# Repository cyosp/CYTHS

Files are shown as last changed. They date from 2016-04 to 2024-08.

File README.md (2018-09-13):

# CYTHS

A 433 MHz Temperature and Humidity Solution

This project is divided in several parts:
 * [A sensor](hardware/sensor/V2.0) which measures and sends temperature and humidity

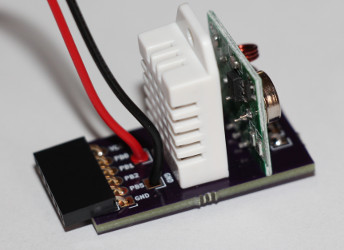
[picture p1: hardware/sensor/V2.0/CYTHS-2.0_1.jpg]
CYTHS-2.0_1
 

 * [A hardware](hardware/piTransceiver/V1.0) part connected to a [Raspberry Pi](https://www.raspberrypi.org/products/) in order to:
    * Receive sensors information
    * Drive RSL switch connected to electric heaters

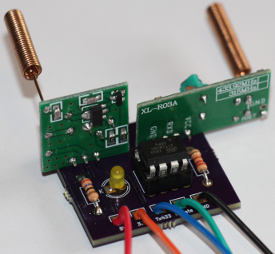
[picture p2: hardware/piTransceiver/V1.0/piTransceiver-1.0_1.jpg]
piTransceiver-1.0_1
    

 * A software part hosted by the [Raspberry Pi](https://www.raspberrypi.org/products/) which:
    * Drives RSL switches

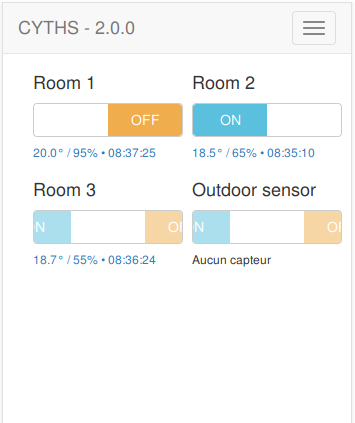
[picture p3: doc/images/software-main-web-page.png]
software-main-web-page
        

    * Stores sensors data received

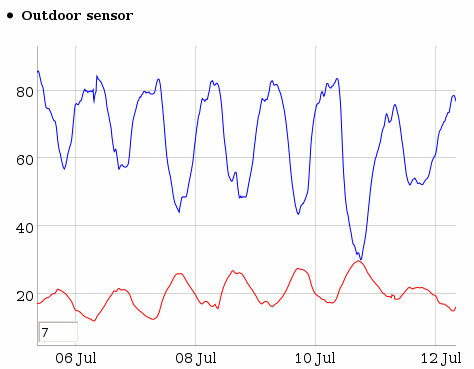
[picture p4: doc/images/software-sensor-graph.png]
software-sensor-graph
        

    * Allow to schedule RSL switches change

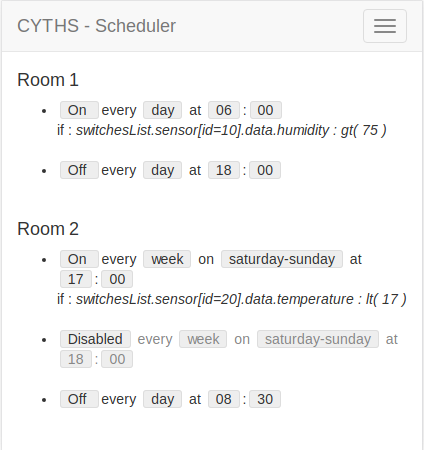
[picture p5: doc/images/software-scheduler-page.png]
software-scheduler-page
        
        
    * Allow to associate and dissociate switches 
        
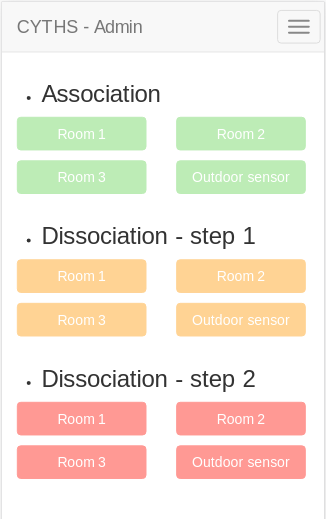
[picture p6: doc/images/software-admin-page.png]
software-admin-page
        

## Hardware requirement

[CYTHS](https://github.com/cyosp/CYTHS) works on [Raspberry Pi](https://www.raspberrypi.org/products/)

It has been tested on models:

 * [Pi 2 Model B](https://www.raspberrypi.org/products/raspberry-pi-2-model-b/)

   Which was used during development phase
 
 * [Pi 3 Model B](https://www.raspberrypi.org/products/raspberry-pi-3-model-b/)
 
   On this board Bluetooth has been added and connected to default UART
 
   To have it working you need:
   
   * Disable Bluetooth to restore default UART

        ```bash
        echo -e "\n# Disable Bluetooth to restore default UART\ndtoverlay=pi3-disable-bt\n" | sudo tee --append /boot/config.txt > /dev/null
        ```
   * Stop Bluetooth service

        ```bash
        sudo systemctl disable hciuart
        ```

    * Make sure you have `console=ttyAMA0` in `/boot/cmdline.txt`

   * And reboot system: `sudo reboot`

## License

**[CYTHS](https://github.com/cyosp/CYTHS)** is released under the BSD 3-Clause License.

See the bundled `LICENSE.md` for details.

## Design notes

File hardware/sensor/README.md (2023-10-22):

## 433 MHz Temperature and Humidity Sensor



### Description

CYTHS is a sensor which is able to send through 433 MHz transmitter a temperature thus a humidity value.

These information are coded on 32 bits and transmitted using the RSL protocol each 5 minutes.

Sensor is low energy consumption allowing to have it working around 1000 days (~2.8 years) with three 1.5V batteries.

Each sensor has an identifier which is initialized following two ways:
 1. On runtime after the first power on.

    After it can be changed later, with this special sequence:
    * Power off
    * Repeat 3 times:
      * Power on
      * Wait between 3 and 6 seconds
      * Power off
	* Power on
 2. On compilation with a special variable defined in source code

### Lifetime

Sensor lifetime is calculated using [Oregon Embedded](http://oregonembedded.com/batterycalc.htm) website and the following information:

| Description | Value |
|:---|:---|
| Capacity rating of battery (mAh) | 1250  |
| Current consumption of device during sleep (mA) | 0.02  |
| Current consumption of device during wake (mA)  | 15 |
| Number of wakeups per hour | 11 |
| Duration of wake time (ms) | 500 |

Estimated battery life is: **1032.29 days, or 2.83 years**.

### Hardware

Sensor is driven by an AVR ATtiny85 microcontroller which is programmed using:
 * The [Tiny AVR Programmer](https://www.sparkfun.com/products/11801)
 * [Arduino IDE](http://www.arduino.org/)

### Code structure

RSL code is based on 32 bits.

They are organized like this:

| 32-31 | 30-29 | 28-25 | 24-1 |
|:---|:---|:---|:---|
| Remote command identifier | Remote command switch position | Switch state to enable (on/off/onoff) | Remote command identifier |

The 4 bits from 25 to 28 never takes value *1111* thus [CYTHS](https://github.com/cyosp/CYTHS) code is organized like this:

| 32-31 | 30-29 | 28-25 | 24-18 | 17-11 | 10-1 |
|:---|:---|:---|:---|:---|:---|
| Battery level | Protocol version | 1111  | Sensor id | Humidity | Temperature |

Where:
 * Battery level
 	* 00 ⇔ 4.35V
 	* 11 ⇔ 4.86V

 * Protocol version
 	* 00 ⇔ First protocol managed and implemented
	It's the one described here

 * 1111
	* Fixed value in order to detect a RSL sensor code

 * Sensor id
	* The sensor identifier
	Value between 1 and 127

 * Humidity
	* Value between 0 and 100
    It matches with the real humidity in %

 * Temperature
	* Value between 0 and 1024
	Real temperature is computed like this:
			T=(Ts-400)/10
    With:
		* T: Real temperature in °C
		* Ts: Temperature coming from sensor
			It means value betwenn 0 and 1024

	At the end it produces the following matching:

		* 0 ⇔ -40.0 °C
		* ...
		* 400 ⇔ 0.0 °C
		* ...
		* 1024 ⇔ 62.4 °C

### Arduino

#### Dependency libraries installation
1. **DHTlib**
   * Sketch → Include Library → Manage Libraries
   * Search **DHTlib** by *Rob Tillaart*
   * Latest version is: *0.1.35* the *2022-08-04*
   * Click *Install*
2. **PinChangeInterrupt**
   * Sketch → Include Library → Manage Libraries 
   * Search **PinChangeInterrupt** by *NicoHood*
   * Latest version is: *1.2.9* the *2022-08-04*
   * Click *Install*
3. **rc-switch** by *CYOSP*
   * Download https://github.com/cyosp/rc-switch/archive/refs/tags/v2.52.1.zip
   * Sketch → Include Library → Add .ZIP Library...
   * Then choose the downloaded ZIP file

#### Configuration

These steps will configure Arduino software in order to use the microcontroller running at 16 Mhz:
 * File → Preferences
  * In *Additional Boards Manager URLs:*
  * Enter *https://raw.githubusercontent.com/damellis/attiny/ide-1.6.x-boards-manager/package_damellis_attiny_index.json*
  * And *OK* button
 * Tools → Board → Boards Manager...
    * Search in the list and select: **attiny** by **David A. Mellis**
    * Click *Install*
    * And *Close* button
 * Tools → Board → ATtiny25/45/85
 * Tools → Processor → ATtiny85
 * Tools → Clock → **Internal** 8 MHz

#### Setup programmer

Here is used [Tiny AVR Programmer](https://www.sparkfun.com/products/11801) and it means:
 * Tools → Programmer → USBtinyISP 
 * Plug the microcontroller on the programmer board or wire the sensor in case of SMD package:

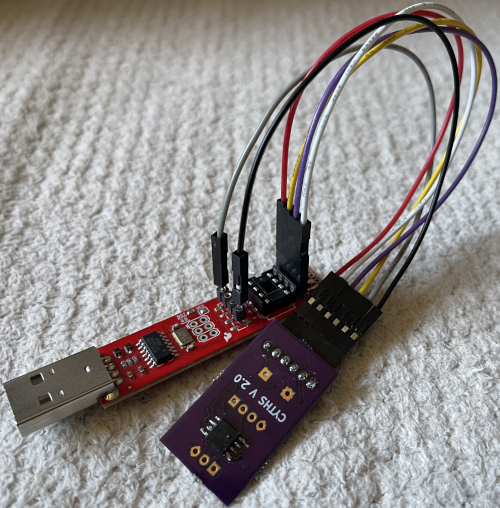
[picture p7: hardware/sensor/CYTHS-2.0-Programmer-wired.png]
CYTHS-2.0-Programmer-wired
   

   **/!\ Photo displays sensor bottom side /!\\**

 * Plug the programmer board to the computer

#### Code upload

It's necessary to burn fuses of the microcontroller to set this configuration:
 * Tools → Burn Bootloader

Output example of burn bootloader in verbose mode:
```
/Applications/Arduino.app/Contents/Java/hardware/tools/avr/bin/avrdude -C/Applications/Arduino.app/Contents/Java/hardware/tools/avr/etc/avrdude.conf -v -v -v -v -pattiny85 -cusbtiny -e -Uefuse:w:0xff:m -Uhfuse:w:0xdf:m -Ulfuse:w:0xe2:m 

avrdude: Version 6.3-20190619
         Copyright (c) 2000-2005 Brian Dean, http://www.bdmicro.com/
         Copyright (c) 2007-2014 Joerg Wunsch

         System wide configuration file is "/Applications/Arduino.app/Contents/Java/hardware/tools/avr/etc/avrdude.conf"
         User configuration file is "/Users/cyosp/.avrduderc"
         User configuration file does not exist or is not a regular file, skipping

         Using Port                    : usb
         Using Programmer              : usbtiny
avrdude: usbdev_open(): Found USBtinyISP, bus:device: 000:005
         AVR Part                      : ATtiny85
         Chip Erase delay              : 400000 us
         PAGEL                         : P00
         BS2                           : P00
         RESET disposition             : possible i/o
         RETRY pulse                   : SCK
         serial program mode           : yes
         parallel program mode         : yes
         Timeout                       : 200
         StabDelay                     : 100
         CmdexeDelay                   : 25
         SyncLoops                     : 32
         ByteDelay                     : 0
         PollIndex                     : 3
         PollValue                     : 0x53
         Memory Detail                 :

                                  Block Poll               Page                       Polled
           Memory Type Mode Delay Size  Indx Paged  Size   Size #Pages MinW  MaxW   ReadBack
           ----------- ---- ----- ----- ---- ------ ------ ---- ------ ----- ----- ---------
           eeprom        65    12     4    0 no        512    4      0  4000  4500 0xff 0xff
                                  Block Poll               Page                       Polled
           Memory Type Mode Delay Size  Indx Paged  Size   Size #Pages MinW  MaxW   ReadBack
           ----------- ---- ----- ----- ---- ------ ------ ---- ------ ----- ----- ---------
           flash         65     6    32    0 yes      8192   64    128 30000 30000 0xff 0xff
                                  Block Poll               Page                       Polled
           Memory Type Mode Delay Size  Indx Paged  Size   Size #Pages MinW  MaxW   ReadBack
           ----------- ---- ----- ----- ---- ------ ------ ---- ------ ----- ----- ---------
           signature      0     0     0    0 no          3    0      0     0     0 0x00 0x00
                                  Block Poll               Page                       Polled
           Memory Type Mode Delay Size  Indx Paged  Size   Size #Pages MinW  MaxW   ReadBack
           ----------- ---- ----- ----- ---- ------ ------ ---- ------ ----- ----- ---------
           lock           0     0     0    0 no          1    0      0  9000  9000 0x00 0x00
                                  Block Poll               Page                       Polled
           Memory Type Mode Delay Size  Indx Paged  Size   Size #Pages MinW  MaxW   ReadBack
           ----------- ---- ----- ----- ---- ------ ------ ---- ------ ----- ----- ---------
           lfuse          0     0     0    0 no          1    0      0  9000  9000 0x00 0x00
                                  Block Poll               Page                       Polled
           Memory Type Mode Delay Size  Indx Paged  Size   Size #Pages MinW  MaxW   ReadBack
           ----------- ---- ----- ----- ---- ------ ------ ---- ------ ----- ----- ---------
           hfuse          0     0     0    0 no          1    0      0  9000  9000 0x00 0x00
                                  Block Poll               Page                       Polled
           Memory Type Mode Delay Size  Indx Paged  Size   Size #Pages MinW  MaxW   ReadBack
           ----------- ---- ----- ----- ---- ------ ------ ---- ------ ----- ----- ---------
           efuse          0     0     0    0 no          1    0      0  9000  9000 0x00 0x00
                                  Block Poll               Page                       Polled
           Memory Type Mode Delay Size  Indx Paged  Size   Size #Pages MinW  MaxW   ReadBack
           ----------- ---- ----- ----- ---- ------ ------ ---- ------ ----- ----- ---------
           calibration    0     0     0    0 no          1    0      0     0     0 0x00 0x00

         Programmer Type : USBtiny
         Description     : USBtiny simple USB programmer, https://learn.adafruit.com/usbtinyisp
avrdude: programmer operation not supported

avrdude: Using SCK period of 10 usec
CMD: [ac 53 00 00] [00 00 53 00]
avrdude: AVR device initialized and ready to accept instructions

Reading | CMD: [30 00 00 00] [00 30 00 1e]
CMD: [30 00 01 00] [00 30 00 93]
################CMD: [30 00 02 00] [00 30 00 0b]
################################## | 100% 0.01s

avrdude: Device signature = 0x1e930b (probably t85)
avrdude: erasing chip
CMD: [ac 80 00 00] [00 ac 80 00]
avrdude: Using SCK period of 10 usec
CMD: [ac 53 00 00] [00 ac 53 00]
avrdude: reading input file "0xff"
avrdude: writing efuse (1 bytes):

/Applications/Arduino.app/Contents/Java/hardware/tools/avr/bin/avrdude -C/Applications/Arduino.app/Contents/Java/hardware/tools/avr/etc/avrdude.conf -v -v -v -v -pattiny85 -cusbtiny 

avrdude: Version 6.3-20190619
         Copyright (c) 2000-2005 Brian Dean, http://www.bdmicro.com/
         Copyright (c) 2007-2014 Joerg Wunsch

         System wide configuration file is "/Applications/Arduino.app/Contents/Java/hardware/tools/avr/etc/avrdude.conf"
         User configuration file is "/Users/cyosp/.avrduderc"
         User configuration file does not exist or is not a regular file, skipping

         Using Port                    : usb
         Using Programmer              : usbtiny
avrdude: usbdev_open(): Found USBtinyISP, bus:device: 000:005
         AVR Part                      : ATtiny85
         Chip Erase delay              : 400000 us
         PAGEL                         : P00
         BS2                           : P00
         RESET disposition             : possible i/o
         RETRY pulse                   : SCK
         serial program mode           : yes
         parallel program mode         : yes
         Timeout                       : 200
         StabDelay                     : 100
         CmdexeDelay                   : 25
         SyncLoops                     : 32
         ByteDelay                     : 0
         PollIndex                     : 3
         PollValue                     : 0x53
         Memory Detail                 :

                                  Block Poll               Page                       Polled
           Memory Type Mode Delay Size  Indx Paged  Size   Size #Pages MinW  MaxW   ReadBack
           ----------- ---- ----- ----- ---- ------ ------ ---- ------ ----- ----- ---------
           eeprom        65    12     4    0 no        512    4      0  4000  4500 0xff 0xff
                                  Block Poll               Page                       Polled
           Memory Type Mode Delay Size  Indx Paged  Size   Size #Pages MinW  MaxW   ReadBack
           ----------- ---- ----- ----- ---- ------ ------ ---- ------ ----- ----- ---------
           flash         65     6    32    0 yes      8192   64    128 30000 30000 0xff 0xff
                                  Block Poll               Page                       Polled
           Memory Type Mode Delay Size  Indx Paged  Size   Size #Pages MinW  MaxW   ReadBack
           ----------- ---- ----- ----- ---- ------ ------ ---- ------ ----- ----- ---------
           signature      0     0     0    0 no          3    0      0     0     0 0x00 0x00
                                  Block Poll               Page                       Polled
           Memory Type Mode Delay Size  Indx Paged  Size   Size #Pages MinW  MaxW   ReadBack
           ----------- ---- ----- ----- ---- ------ ------ ---- ------ ----- ----- ---------
           lock           0     0     0    0 no          1    0      0  9000  9000 0x00 0x00
                                  Block Poll               Page                       Polled
           Memory Type Mode Delay Size  Indx Paged  Size   Size #Pages MinW  MaxW   ReadBack
           ----------- ---- ----- ----- ---- ------ ------ ---- ------ ----- ----- ---------
           lfuse          0     0     0    0 no          1    0      0  9000  9000 0x00 0x00
                                  Block Poll               Page                       Polled
           Memory Type Mode Delay Size  Indx Paged  Size   Size #Pages MinW  MaxW   ReadBack
           ----------- ---- ----- ----- ---- ------ ------ ---- ------ ----- ----- ---------
           hfuse          0     0     0    0 no          1    0      0  9000  9000 0x00 0x00
                                  Block Poll               Page                       Polled
           Memory Type Mode Delay Size  Indx Paged  Size   Size #Pages MinW  MaxW   ReadBack
           ----------- ---- ----- ----- ---- ------ ------ ---- ------ ----- ----- ---------
           efuse          0     0     0    0 no          1    0      0  9000  9000 0x00 0x00
                                  Block Poll               Page                       Polled
           Memory Type Mode Delay Size  Indx Paged  Size   Size #Pages MinW  MaxW   ReadBack
           ----------- ---- ----- ----- ---- ------ ------ ---- ------ ----- ----- ---------
           calibration    0     0     0    0 no          1    0      0     0     0 0x00 0x00

         Programmer Type : USBtiny
         Description     : USBtiny simple USB programmer, https://learn.adafruit.com/usbtinyisp
avrdude: programmer operation not supported

avrdude: Using SCK period of 10 usec
Writing | CMD: [50 08 00 00] [00 50 08 ff]
################################################## | 100% 0.00s

avrdude: 1 bytes of efuse written
avrdude: verifying efuse memory against 0xff:
avrdude: load data efuse data from input file 0xff:
avrdude: input file 0xff contains 1 bytes
avrdude: reading on-chip efuse data:

Reading | CMD: [50 08 00 00] [00 50 08 ff]
################################################## | 100% 0.00s

avrdude: verifying ...
avrdude: 1 bytes of efuse verified
avrdude: reading input file "0xdf"
avrdude: writing hfuse (1 bytes):

Writing | CMD: [58 08 00 00] [00 58 08 df]
################################################## | 100% 0.00s

avrdude: 1 bytes of hfuse written
avrdude: verifying hfuse memory against 0xdf:
avrdude: load data hfuse data from input file 0xdf:
avrdude: input file 0xdf contains 1 bytes
avrdude: reading on-chip hfuse data:

Reading | CMD: [58 08 00 00] [00 58 08 df]
################################################## | 100% 0.00s

avrdude: verifying ...
avrdude: 1 bytes of hfuse verified
avrdude: reading input file "0xe2"
avrdude: writing lfuse (1 bytes):

Writing | CMD: [50 00 00 00] [00 50 00 f1]
CMD: [ac a0 00 e2] [00 ac a0 00]
CMD: [50 00 00 00] [e2 50 00 ff]
CMD: [50 00 00 00] [00 50 00 e2]
################################################## | 100% 0.01s

avrdude: 1 bytes of lfuse written
avrdude: verifying lfuse memory against 0xe2:
avrdude: load data lfuse data from input file 0xe2:
avrdude: input file 0xe2 contains 1 bytes
avrdude: reading on-chip lfuse data:

Reading | CMD: [50 00 00 00] [00 50 00 e2]
################################################## | 100% 0.00s

avrdude: verifying ...
avrdude: 1 bytes of lfuse verified

avrdude done.  Thank you.

CMD: [ac 53 00 00] [00 00 53 00]
avrdude: AVR device initialized and ready to accept instructions

Reading | CMD: [30 00 00 00] [00 30 00 1e]
CMD: [30 00 01 00] [00 30 00 93]
################CMD: [30 00 02 00] [00 30 00 0b]
################################## | 100% 0.01s

avrdude: Device signature = 0x1e930b (probably t85)

avrdude done.  Thank you.
```

Then **Upload** button of Arduino IDE can be used to upload code to the microcontroller.

Output example of an upload in verbose mode:
```
Sketch uses 5086 bytes (62%) of program storage space. Maximum is 8192 bytes.
Global variables use 218 bytes (42%) of dynamic memory, leaving 294 bytes for local variables. Maximum is 512 bytes.
/Applications/Arduino.app/Contents/Java/hardware/tools/avr/bin/avrdude -C/Applications/Arduino.app/Contents/Java/hardware/tools/avr/etc/avrdude.conf -v -pattiny85 -cusbtiny -Uflash:w:/var/folders/0m/mk12ygtj6vvc6_7bwsyj_v5w0000gp/T/arduino_build_649299/CYTHS.ino.hex:i 

avrdude: Version 6.3-20190619
         Copyright (c) 2000-2005 Brian Dean, http://www.bdmicro.com/
         Copyright (c) 2007-2014 Joerg Wunsch

         System wide configuration file is "/Applications/Arduino.app/Contents/Java/hardware/tools/avr/etc/avrdude.conf"
         User configuration file is "/Users/cyosp/.avrduderc"
         User configuration file does not exist or is not a regular file, skipping

         Using Port                    : usb
         Using Programmer              : usbtiny
avrdude: usbdev_open(): Found USBtinyISP, bus:device: 000:005
         AVR Part                      : ATtiny85
         Chip Erase delay              : 400000 us
         PAGEL                         : P00
         BS2                           : P00
         RESET disposition             : possible i/o
         RETRY pulse                   : SCK
         serial program mode           : yes
         parallel program mode         : yes
         Timeout                       : 200
         StabDelay                     : 100
         CmdexeDelay                   : 25
         SyncLoops                     : 32
         ByteDelay                     : 0
         PollIndex                     : 3
         PollValue                     : 0x53
         Memory Detail                 :

                                  Block Poll               Page                       Polled
           Memory Type Mode Delay Size  Indx Paged  Size   Size #Pages MinW  MaxW   ReadBack
           ----------- ---- ----- ----- ---- ------ ------ ---- ------ ----- ----- ---------
           eeprom        65    12     4    0 no        512    4      0  4000  4500 0xff 0xff
           flash         65     6    32    0 yes      8192   64    128 30000 30000 0xff 0xff
           signature      0     0     0    0 no          3    0      0     0     0 0x00 0x00
           lock           0     0     0    0 no          1    0      0  9000  9000 0x00 0x00
           lfuse          0     0     0    0 no          1    0      0  9000  9000 0x00 0x00
           hfuse          0     0     0    0 no          1    0      0  9000  9000 0x00 0x00
           efuse          0     0     0    0 no          1    0      0  9000  9000 0x00 0x00
           calibration    0     0     0    0 no          1    0      0     0     0 0x00 0x00

         Programmer Type : USBtiny
         Description     : USBtiny simple USB programmer, https://learn.adafruit.com/usbtinyisp
avrdude: programmer operation not supported

avrdude: Using SCK period of 10 usec
avrdude: AVR device initialized and ready to accept instructions

Reading | ################################################## | 100% 0.01s

avrdude: Device signature = 0x1e930b (probably t85)
avrdude: NOTE: "flash" memory has been specified, an erase cycle will be performed
         To disable this feature, specify the -D option.
avrdude: erasing chip
avrdude: Using SCK period of 10 usec
avrdude: reading input file "/var/folders/0m/mk12ygtj6vvc6_7bwsyj_v5w0000gp/T/arduino_build_649299/CYTHS.ino.hex"
avrdude: writing flash (5086 bytes):

Writing | ################################################## | 100% 8.46s

avrdude: 5086 bytes of flash written
avrdude: verifying flash memory against /var/folders/0m/mk12ygtj6vvc6_7bwsyj_v5w0000gp/T/arduino_build_649299/CYTHS.ino.hex:
avrdude: load data flash data from input file /var/folders/0m/mk12ygtj6vvc6_7bwsyj_v5w0000gp/T/arduino_build_649299/CYTHS.ino.hex:
avrdude: input file /var/folders/0m/mk12ygtj6vvc6_7bwsyj_v5w0000gp/T/arduino_build_649299/CYTHS.ino.hex contains 5086 bytes
avrdude: reading on-chip flash data:

Reading | ################################################## | 100% 12.97s

avrdude: verifying ...
avrdude: 5086 bytes of flash verified

avrdude done.  Thank you.
```

#### Code re-upload

Reprogram microcontroller could be hard due to its deep sleep mode.

In that case you must try several times and you will succeed to re-upload a new version.

If needed, try to reburn bootloader until successful.

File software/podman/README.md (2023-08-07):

# Podman instructions

## Build in local
```bash
podman build .. -f Containerfile -t cyths
```

## Run from registry

### On Raspberry Pi model 3 and Debian Bookworm
 - Disable Bluetooth
```bash
sudo perl -i -pe "s/^(console.*)$/dtoverlay=disable-bt \1/" /boot/firmware/cmdline.txt
```
 - Disable default process attached to the serial port
```bash
sudo systemctl stop serial-getty@ttyS1.service
sudo systemctl mask serial-getty@ttyS1.service
```
 - Map serial port and GPIO adding these options to `podman run`
```bash
--device=/dev/ttyS1
--device=/dev/gpiochip0
```

### With no data
```
podman run \
   -d \
   -p 8080:80 \
   --name cyths \
   docker.io/cyosp/cyths:6.6.0
```

### Demo
 - Ensure `config.json` is writable by *everybody* to be updated inside container
```
podman run \
    -d \
    -p 8080:80 \
    -v ./demo/data/config.json:/etc/cyths/config.json \
    -v ./demo/data/csv:/var/lib/cyths/csv \
    --name cyths-demo \
    docker.io/cyosp/cyths:6.6.0
```

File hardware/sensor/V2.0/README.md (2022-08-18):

## 433 MHz Temperature and Humidity Sensor

CYTHS-2.0_1

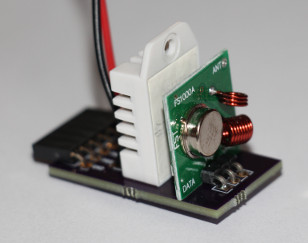
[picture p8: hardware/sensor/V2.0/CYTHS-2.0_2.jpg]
CYTHS-2.0_2


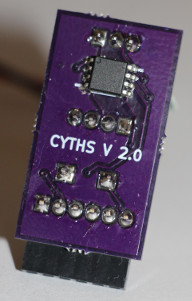
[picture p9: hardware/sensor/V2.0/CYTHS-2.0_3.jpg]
CYTHS-2.0_3


### Printed Circuit Board (PCB)

PCB is double layers and has been:
 * Designed using: [KiCad](http://kicad-pcb.org)
 * Printed with: [OSHPARK](https://oshpark.com)

&nbsp;&nbsp;&nbsp;&nbsp;&nbsp;&nbsp;CYTHS-2.0-PCB-F&nbsp;&nbsp;&nbsp;&nbsp;&nbsp;CYTHS-2.0-PCB-B

### Components

| Description | Reference | Power (V) |
|:---|:---|---|
| Temperature and humidity sensor | [DHT22](https://www.waveshare.com/wiki/DHT22_Temperature-Humidity_Sensor) | 3.3 → 6 |
| Microcontroller | [ATTINY85-20SU](https://www.microchip.com/en-us/product/attiny85) | 2.7 → 5.5 |
| 433 MHz transmitter | [433 MHz transmitter](https://microcontrollerslab.com/433mhz-rf-transmitter-module-pinout-examples-applications/) | 3.3 → 12  |
| 3x 1.5V AAA batteries | [Camelion batteries](http://camelionbatteries.com/primary/plus.html) | 1.5 |

#### ATtiny85 pin mapping

```
PB5 -| °   |- VCC
PB3 -|     |- PB2
PB4 -|     |- PB1
GND -|     |- PB0
```

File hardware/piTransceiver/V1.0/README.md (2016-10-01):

## piTransceiver

[Raspberry Pi](https://www.raspberrypi.org/products/) extension board to receive and transmit to 433MHz.

piTransceiver-1.0_1

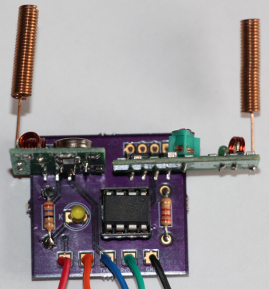
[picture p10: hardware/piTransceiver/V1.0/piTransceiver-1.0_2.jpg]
piTransceiver-1.0_2


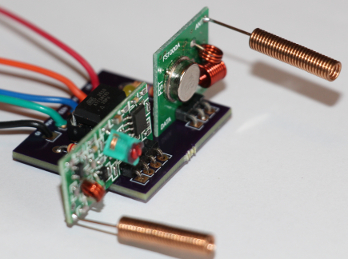
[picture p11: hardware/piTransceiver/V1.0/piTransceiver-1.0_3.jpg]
piTransceiver-1.0_3


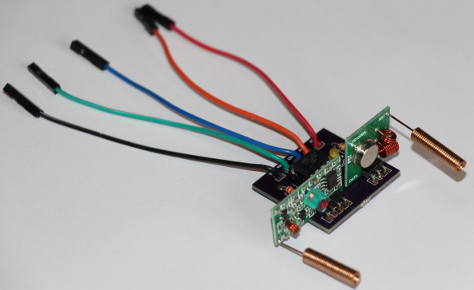
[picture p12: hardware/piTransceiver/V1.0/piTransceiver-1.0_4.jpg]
piTransceiver-1.0_4


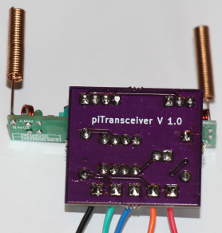
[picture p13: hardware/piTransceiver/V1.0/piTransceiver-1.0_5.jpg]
piTransceiver-1.0_5


#### PCB

piTransceiver is composed of a double layer PCB:

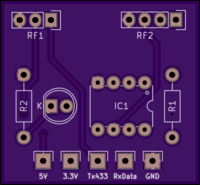
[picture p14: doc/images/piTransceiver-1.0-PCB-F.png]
piTransceiver-1.0-PCB-F
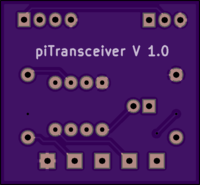
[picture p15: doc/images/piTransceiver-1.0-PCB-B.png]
piTransceiver-1.0-PCB-B
&nbsp;&nbsp;&nbsp;&nbsp;&nbsp;&nbsp;&nbsp;&nbsp;&nbsp;&nbsp;&nbsp;

### Components

Components used are:

| Component | Reference |
|:---|:---|
| R1 | 2.2 KΩ 5% |
| R2 | 27 Ω 5% |
| LED | Yellow LED |
| IC1 | ATtiny85-20PU |
| RF1 | 433 MHz transmitter + spring antenna |
| RF2 | 433 MHz receiver + spring antenna |

#### Configuration

These steps will configure Arduino software in order to use the microcontroller running at 16 Mhz:
 * File -> Preferences
  * In *Additional Boards Manager URLs:*
  * Enter *https://raw.githubusercontent.com/damellis/attiny/ide-1.6.x-boards-manager/package_damellis_attiny_index.json*
  * And *OK* button
 * Tools -> Board-> Boards Manager...
    * Search in the list and select: **attiny** by **David A. Mellis**
    * Click *Install*
    * And *Close* button
 * Tools -> Board-> ATtiny25/45/85
 * Tools -> Processor-> ATtiny85
 * Tools -> Clock-> Internal 16 MHz
 * Tools -> Programmer-> USBtinyISP

Then it's necessary to burn fuses of the microcontroller to set this configuration.
Steps are:
 * Plug a microcontroller on the [Tiny AVR Programmer](https://www.sparkfun.com/products/11801)
 * Plug the [Tiny AVR Programmer](https://www.sparkfun.com/products/11801) to the computer
 * Tools -> Burn Bootloader

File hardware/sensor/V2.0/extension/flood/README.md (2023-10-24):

# Flood extension

Flood sensor can be plugged on v2 sensor programmation pins.

## Pin mapping

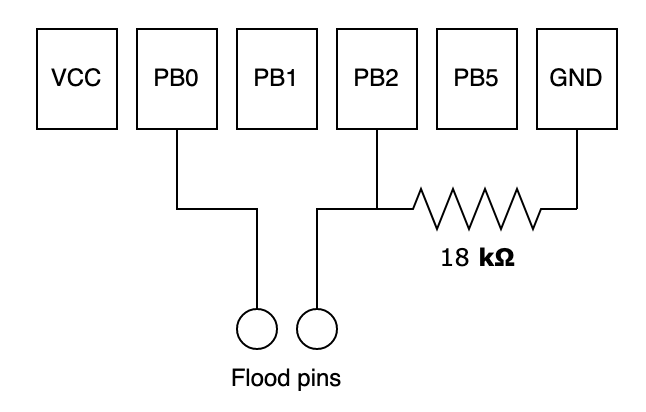
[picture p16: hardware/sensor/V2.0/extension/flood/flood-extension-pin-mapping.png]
Flood extension pin mapping


## Firmware

In [sensor.ino](../../../sensor.ino) uncomment `FLOOD_SENSOR_V2_ID` and choose the flood sensor ID.

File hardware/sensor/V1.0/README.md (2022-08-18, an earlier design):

## 433 MHz Temperature and Humidity Sensor

CYTHS

### Printed Circuit Board (PCB)

PCB has been designed and printed with: [Fritzing](http://fritzing.org)

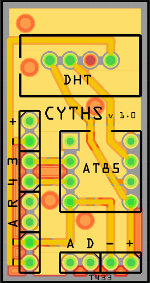
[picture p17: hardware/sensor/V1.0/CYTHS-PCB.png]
CYTHS-PCB CYTHS


### Components

Components used are:

| Description | Reference |
|:---|:---|
| Temperature and humidity sensor | [DHT22](https://www.waveshare.com/wiki/DHT22_Temperature-Humidity_Sensor) |
| Microcontroller | [ATTINY85-20PU](https://www.microchip.com/en-us/product/attiny85) |
| 433 MHz transmitter | [433 MHz transmitter](https://microcontrollerslab.com/433mhz-rf-transmitter-module-pinout-examples-applications/) |
| 3x 1.5V AAA batteries | [Camelion batteries](http://camelionbatteries.com/primary/plus.html) |

#### ATtiny85 pin mapping

```
PB5 -| °   |- VCC
PB3 -|     |- PB2
PB4 -|     |- PB1
GND -|     |- PB0
```

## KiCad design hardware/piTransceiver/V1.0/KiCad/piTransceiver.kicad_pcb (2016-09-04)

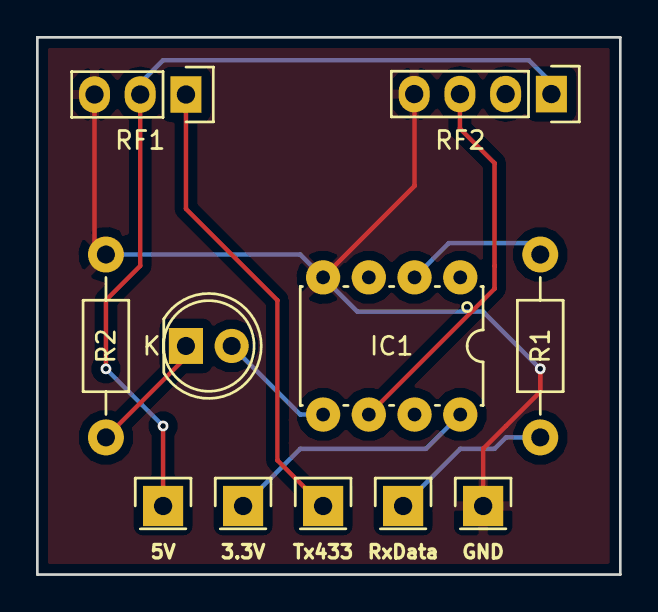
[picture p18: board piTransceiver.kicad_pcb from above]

Board: 2 copper layers, 32.4 x 29.8 mm, 5 parts (0 on the bottom side), 4 nets.

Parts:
IC1: ATTINY85-S; PDIP-8
R1, R2: Resistor_Horizontal_RM10mm
RF1: RF_Transmitter_433_MHz
RF2: RF_Receiver_433_MHz

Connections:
+5V: RF1.2, RF2.1
GND: IC1.4, R2.1, RF1.3, RF2.4
unnamed: IC1.2, R1.1
unnamed: IC1.6, RF2.3

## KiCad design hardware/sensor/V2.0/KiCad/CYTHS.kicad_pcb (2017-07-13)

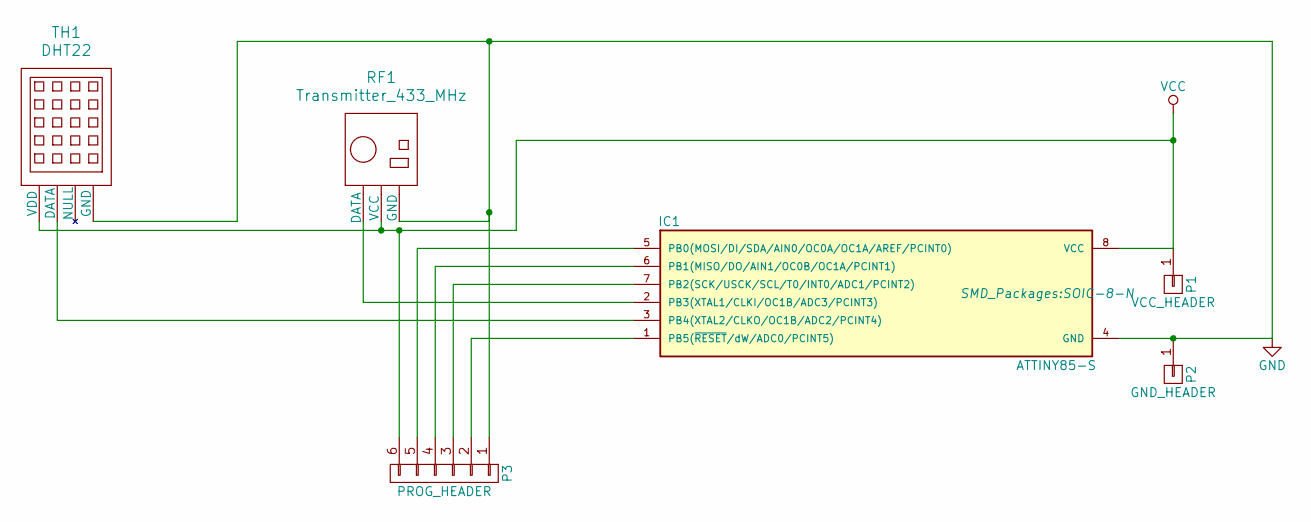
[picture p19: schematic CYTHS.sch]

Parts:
IC1: ATTINY85-S; SOIC-8-N
P1: VCC_HEADER; Pin_Header_Straight_1x01
P2: GND_HEADER; Pin_Header_Straight_1x01
P3: PROG_HEADER; Pin_Header_Angled_1x06
RF1: Transmitter_433_MHz; RF_Transmitter_433_MHz
TH1: DHT22; DHT22_Temperature_Humidity

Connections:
GND: IC1.4 (GND), P2.1, P3.1, RF1.3 (GND), TH1.4 (GND)
unnamed: IC1.1 (PB5(~RESET~/dW/ADC0/PCINT5)), P3.2
unnamed: IC1.2 (PB3(XTAL1/CLKI/OC1B/ADC3/PCINT3)), RF1.1 (DATA)
unnamed: IC1.3 (PB4(XTAL2/CLKO/OC1B/ADC2/PCINT4)), TH1.2 (DATA)
unnamed: IC1.5 (PB0(MOSI/DI/SDA/AIN0/OC0A/OC1A/AREF/PCI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), P3.5
unnamed: IC1.6 (PB1(MISO/DO/AIN1/OC0B/OC1A/PCINT1)), P3.4
unnamed: IC1.7 (PB2(SCK/USCK/SCL/T0/INT0/ADC1/PCINT2)), P3.3
VCC: IC1.8 (VCC), P1.1, P3.6, RF1.2 (VCC), TH1.1 (VDD)

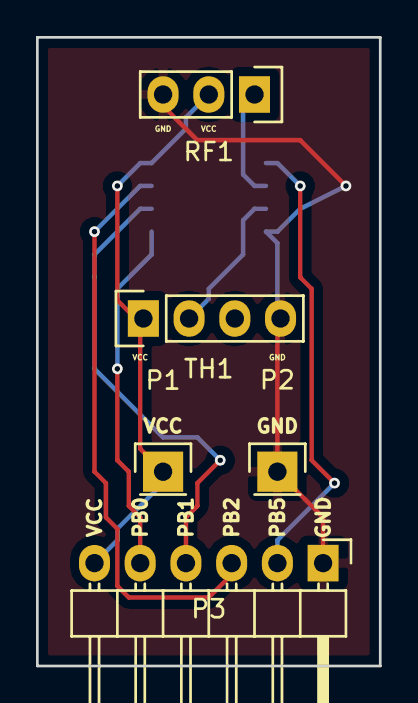
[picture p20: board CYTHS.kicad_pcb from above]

Board: 2 copper layers, 19.0 x 34.9 mm, 6 parts (1 on the bottom side), 8 nets.

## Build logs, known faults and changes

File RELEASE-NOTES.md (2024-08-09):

Release notes
-------------
##### 6.10.0 (2024-08-08)
 * cyths-update: Move updated date to sensor decoded info in a new log format 

##### 6.9.0 (2023-12-24)
 * Add switch separator
 * Add switch with sensor in splited view

##### 6.8.0 (2023-09-28)
 * Update endpoint can take several values

##### 6.7.0 (2023-08-25)
 * Set local time and time zone according to TZ variable

##### 6.6.0 (2023-08-07)
 * Expose csv and rrd directories as container image volumes

##### 6.5.0 (2023-08-07)
 *  Build container image with rc-rsl 2.1.0

##### 6.4.0 (2023-08-03)
 * Update to work behind a reverse proxy
 * Build container image with empty cyths-update log file

##### 6.3.1 (2023-08-01)
 * cyths-update: Avoid Bash error if sensor value received is not registered

##### 6.3.0 (2023-07-31)
 * Add arm64v8 container image generation

##### 6.2.0 (2023-07-31)
 * Automate container image generation
 * cyths-receiver: Check ttyS1 availability if ttyAMA0 doesn't exist

##### 6.1.1 (2023-07-22)
 * Fix: Display all sensors graph instead of the asked one

##### 6.1.0 (2023-07-22)
 * Add endpoint to update CYTHS value

##### 6.0.0 (2023-07-20)
 * Move to container packaging

##### 5.0.1 (2023-07-17)
 * Fix: Incorrect require path for JSONPath library

##### 5.0.0 (2023-07-15)
 * /!\ Crontab condition breaking change /!\
   - Condition expression move from NodeJS/json-query to PHP/JSONPath
   - Comparison operators move from: gt, ge, ... to standard ones: >, >=, ...
   - Restrict JSON path evaluation to left condition side
 * Dependency changes:
   * Remove NodeJS
   * PHP >= 8.0
 * Log received code as decimal value

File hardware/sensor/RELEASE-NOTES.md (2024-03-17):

Release notes
-------------
##### 2.4.0 (2024-03-17)
 * Add optional step up module

##### 2.3.1 (2023-10-23)
 * Add flood sensor capability to V2 sensor

##### 2.3.1 (2022-08-14)
 * Fix: Code not working for sensor V1.0

##### 2.3.0 (2022-08-13)
 * Improve battery voltage mapping and fact it can only down

##### 2.2.0 (2022-08-11)
 * Battery level is updated only each 6 hours instead of each measure

##### 2.1.0 (2022-08-10)
 * Sensor id can be chosen using a static variable

##### 2.0.0 (2016-08-30)
 * Version updated according to hardware CYTHS V 2.0

##### 1.0.3 (2016-06-15)
 * Transmission period is now set to 5 minutes and repeat transmission is divided by two in order to preserve power consumption

##### 1.0.2 (2016-05-21)
 * Random generator is now initialized with a DHT read as it improves the random generation of sensor id

##### 1.0.1 (2016-04-14)
 * Improve battery life which now respects the project aim with battery life estimated around 3.5 years

##### 1.0.0 (2016-02-21)
 * Initial release

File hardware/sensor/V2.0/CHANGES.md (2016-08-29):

### V 2.0.0 2016-08-29
 - Add KiCad files for the hardware part

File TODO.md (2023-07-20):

# TODO
 - [podman] Split in several containers via podman-compose

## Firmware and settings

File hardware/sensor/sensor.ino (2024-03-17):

// Temperature and humidity sensor using RSL protocol

// Uncomment for sensor V1.0
// #define SENSOR_V1

// Uncomment to choose sensor id
// Value range: 1 - 127
// #define STATIC_SENSOR_ID 51

// Uncomment for flood sensor capability to V2 sensor
// #define FLOOD_SENSOR_V2_ID 15

// To reduce power consumption
#include <avr/sleep.h>
// For DHT sensor
#include <dht.h>
// For wireless transmission
#include <RCSwitch.h>
// To save data even when power is off
#include <EEPROM.h>


// Clear Bit of an I/O register
// Set to 0
#ifndef cbi
#define cbi(sfr, bit) (_SFR_BYTE(sfr) &= ~_BV(bit))
#endif
// Set Bit of an I/O register
// Set to 1
#ifndef sbi
#define sbi(sfr, bit) (_SFR_BYTE(sfr) |= _BV(bit))
#endif

// Define low frequency factor
// It has an impact on delay function
// /!\ Modify this value must be set according CLKPR in setLowFreq function
#define LOW_FREQ_FACTOR 256

#ifdef SENSOR_V1
  #define POWER_DHT_AND_TRANSMITTER   0
  #define TRANSMITTER_433_PIN         1
  #define DHT_PIN                     2
  #define STEP_UP_PIN                 3

  #define UNUSED_PIN_1                4
  #define UNUSED_PIN_2                5
#else
  #define TRANSMITTER_433_PIN         3
  #define DHT_PIN                     4

  #define STEP_UP_PIN                 0

  #define FLOOD_POWER_PIN             0
  #ifdef FLOOD_SENSOR_V2_ID
    #define FLOOD_CHECK_PIN          A1 // Analogical pin 1 (A1) matches digital pin 2
    const unsigned long floodSensorV2Id = FLOOD_SENSOR_V2_ID;
  #else
    #define FLOOD_CHECK_PIN           2
  #endif

  #define UNUSED_PIN_1                1
  #define UNUSED_PIN_2                5
#endif

// Low power consumption values
#define WATCHDOG      9                 // 9 => 8,3 seconds
#define WATCHDOB_NBR  36                // 36 <=> 5 minutes (299 seconds)
#define WATCHDOB_COUNT_TO_READ_POWER 36 // 36 * 5 minutes <=> 6 hours

// Watchdog interrupt number
volatile int index = WATCHDOB_NBR;
unsigned int watchdogCount = WATCHDOB_COUNT_TO_READ_POWER;

RCSwitch mySwitch = RCSwitch();
dht DHT;

unsigned long batteryLevel = 4;

// Define protocol (00) and code (1111)
unsigned long protocolAndCode = 15;

// Used to define if sensor identifier must be reseted
int resetSensorId = 0;
// Used to define lenght to read in EEPROM for reset sensor id
int bitLength_16 = 0;
// Position in EEPROM for sensor id reset number
int resetSensorIdInEEPROM = 0;

// Sensor identifier
unsigned long sensorId = 0;
// Used to define lenght to read in EEPROM for sensor id
// 32 bits are used for shift operations
unsigned long bitLength_32 = 0;
// Position in EEPROM for sensor id
unsigned long sensorIdInEEPROM = 0 + sizeof( resetSensorIdInEEPROM );

void setup() {
  // Set microcontroller to low frequency
  // TO ENABLE AT THE END BECAUSE AFTER IT'S MORE DIFFICULT TO PROGRAM AGAIN ATtiny85
  //setLowFreq();

  // Disable ADC
  ADCSRA = 0;

  // Define pin states
  pinMode(DHT_PIN, INPUT);
  pinMode(STEP_UP_PIN, OUTPUT);
  pinMode(UNUSED_PIN_1, OUTPUT);
  pinMode(UNUSED_PIN_2, OUTPUT);

  // Set to low level unused pins
  digitalWrite(STEP_UP_PIN, LOW);
  digitalWrite(UNUSED_PIN_1, LOW);
  digitalWrite(UNUSED_PIN_2, LOW);

  #ifdef SENSOR_V1
    pinMode(POWER_DHT_AND_TRANSMITTER, OUTPUT);
    digitalWrite(POWER_DHT_AND_TRANSMITTER, HIGH);
  #else
    pinMode(FLOOD_POWER_PIN, OUTPUT);
    digitalWrite(FLOOD_POWER_PIN, LOW);
    #ifdef FLOOD_SENSOR_V2_ID
      pinMode(FLOOD_CHECK_PIN, INPUT);
    #else
      pinMode(FLOOD_CHECK_PIN, OUTPUT);
      digitalWrite(FLOOD_CHECK_PIN, LOW);
    #endif
  #endif

  mySwitch.enableTransmit( TRANSMITTER_433_PIN );
  // Protocol: 2 <=> rc-rsl
  mySwitch.setProtocol( 2 );
  mySwitch.setRepeatTransmit( 5 );

  //
  // Manage sensor id reset part
  //
  #ifndef STATIC_SENSOR_ID
    resetSensorId = EEPROM.get( resetSensorIdInEEPROM , bitLength_16 );
    resetSensorId++;
    // Avoid false restart because being pluging battery
    delay( 3000 /*/ LOW_FREQ_FACTOR*/ );
    EEPROM.put( resetSensorIdInEEPROM , resetSensorId );
    // Let choice to user to unconnect battery
    delay( 3000 /*/ LOW_FREQ_FACTOR*/ );
    if( resetSensorId >= 3 ) {
      sensorId = 0;
      EEPROM.put( sensorIdInEEPROM , sensorId );
    }

    resetSensorId = 0;
    EEPROM.put( resetSensorIdInEEPROM , resetSensorId );

    //
    // Generate a new sensor id if needed
    //  => First power on
    //  => Asked by user with 3 reboots
    //     Each one more than 3 seconds and less than 6 seconds
    //
    sensorId = EEPROM.get( sensorIdInEEPROM , bitLength_32 );
    if( sensorId == 0 ) {
      // Init random generator with a DHT read
      DHT.read22( DHT_PIN );
      randomSeed( DHT.temperature * DHT.humidity );

      sensorId = random( 1 , 127 );
      EEPROM.put( sensorIdInEEPROM , sensorId );
    }
  #else
    sensorId = STATIC_SENSOR_ID;
    // Wait same time as random sensor id phase
    // It allows also to have a correct DHT measure
    delay( 6000 /*/ LOW_FREQ_FACTOR*/ );
  #endif

  // Manage low energy
  setup_watchdog( WATCHDOG );
}

void switchAnalogToDigitalConverterOn() {
  sbi( ADCSRA , ADEN );
}

void switchAnalogToDigitalConverterOff() {
  cbi( ADCSRA , ADEN );
}

void loop() {
  // It's time to get sensor values
  if( index >= WATCHDOB_NBR )
  {
    index = 0;

    // Set microcontroller to high frequency
    setHighFreq();

    unsigned long vcc = readVcc();
    if(watchdogCount >= WATCHDOB_COUNT_TO_READ_POWER) {
        watchdogCount = 0;
    } else {
        watchdogCount++;
    }

    unsigned long chk = DHT.read22( DHT_PIN );

    // Set microcontroller to low frequency
    setLowFreq();

    // Battery voltage mapping per element
    // 1.5V : full capacity
    // 1.3V : 60% to 80% capacity
    // 1.2V : 30% to 60% capacity
    // 1.0V : empty
    unsigned long vccMapping = 0;
    if(vcc>=4500) {
      vccMapping = 3;
    } else if (vcc>=3900) {
      vccMapping = 2;
    } else if (vcc>=3600) {
      vccMapping = 1;
    }
    // Battery voltage can only down
    // It avoids battery level to up and down near threshold
    if(vccMapping<batteryLevel) {
      batteryLevel = vccMapping;
    }

    unsigned long hum = (unsigned long) DHT.humidity;
    // Get temperature * 10
    unsigned long temp = (unsigned long) (DHT.temperature * 10.0 );
    // Adjust temperature in order to have it in the range 0 -> 1024
    temp = map( temp , -400 , 624 , 0 , 1024 );

    // "Manage" sensor library feedback codes
    switch( chk )
    {
      case DHTLIB_OK:
          break;
      case DHTLIB_ERROR_CHECKSUM:
          hum = temp = 100;
          break;
      case DHTLIB_ERROR_TIMEOUT:
          hum = temp = 200;
          break;
      case DHTLIB_ERROR_CONNECT:
          hum = temp = 300;
          break;
      case DHTLIB_ERROR_ACK_L:
         hum = temp = 400;
          break;
      case DHTLIB_ERROR_ACK_H:
          hum = temp = 500;
          break;
      default:
         hum = temp = 600;
          break;
    }

    // RSL code details
    // [2 bits/battery level] + [2 bits/protocol version] + [4 bits/1111 <=> rsl code not used] + [7 bits/sensor id] + [7 bits/humidity] + [10 bits/temperature]

    // Compute RSL code
    unsigned long code = batteryLevel << 30 | protocolAndCode << 24 | sensorId << 17 | hum << 10 | temp;

    digitalWrite(STEP_UP_PIN, HIGH);
    setHighFreq();
    mySwitch.send( code , 32 );
    digitalWrite(STEP_UP_PIN, LOW);

    #ifdef FLOOD_SENSOR_V2_ID
      switchAnalogToDigitalConverterOn();
      digitalWrite(FLOOD_POWER_PIN, HIGH);
      delay( 100 );
      int flood = analogRead(FLOOD_CHECK_PIN); // value is: 0 -> 1024
      digitalWrite(FLOOD_POWER_PIN, LOW);
      switchAnalogToDigitalConverterOff();

      hum = map( flood , 0 , 1024 , 0 , 100 );
      temp = map( flood , 0 , 1024 , 400 , 900 );

      // Compute RSL code
      code = batteryLevel << 30 | protocolAndCode << 24 | floodSensorV2Id << 17 | hum << 10 | temp;

      delay( 1500 ); // Wait receiver has managed first code before to send flood info

      digitalWrite(STEP_UP_PIN, HIGH);
      mySwitch.send( code , 32 );
      digitalWrite(STEP_UP_PIN, LOW);
    #endif

    setLowFreq();
  }

   // Set microcontroller in sleep mode
   system_sleep();
}

// Set system into the sleep state
// System wakes up when watchdog is timed out
void system_sleep() {
  // Set sleep mode
  set_sleep_mode( SLEEP_MODE_PWR_DOWN );
  // System sleeps here
  sleep_mode();
}

// Configure watchdog time out
// 0 => 16ms
// 1 => 32ms
// 2 => 64ms
// 3 => 128ms
// 4 => 250ms
// 5 => 500ms
// 6 => 1sec
// 7 => 2secs
// 8 => 4secs
// 9 => 8secs
void setup_watchdog( int ii ) {
  byte bb;
  int ww;

  if( ii > 9 ) ii = 9;
  bb = ii & 7;

  if( ii > 7 ) bb |= (1<<5);
  bb |= (1<<WDCE);

  ww = bb;

  MCUSR &= ~(1<<WDRF);
  // Start timed sequence
  WDTCR |= (1<<WDCE) | (1<<WDE);
  // Set new watchdog timeout value
  WDTCR = bb;
  WDTCR |= _BV(WDIE);
}

// Watchdog Interrupt Service
// Is executed when watchdog timed out
ISR( WDT_vect ) {
  index++;
}

// Measure input microcontroller voltage against internal 1.1V
// Return Vcc value in mV
long readVcc() {
  switchAnalogToDigitalConverterOn();

  // Read 1.1V reference against Vcc
  // Set the reference to Vcc and the measurement to the internal 1.1V reference
  #if defined(__AVR_ATmega32U4__) || defined(__AVR_ATmega1280__) || defined(__AVR_ATmega2560__)
    ADMUX = _BV(REFS0) | _BV(MUX4) | _BV(MUX3) | _BV(MUX2) | _BV(MUX1);
  #elif defined (__AVR_ATtiny24__) || defined(__AVR_ATtiny44__) || defined(__AVR_ATtiny84__)
    ADMUX = _BV(MUX5) | _BV(MUX0);
  #elif defined (__AVR_ATtiny25__) || defined(__AVR_ATtiny45__) || defined(__AVR_ATtiny85__)
    ADMUX = _BV(MUX3) | _BV(MUX2);
  #else
    ADMUX = _BV(REFS0) | _BV(MUX3) | _BV(MUX2) | _BV(MUX1);
  #endif

  // Wait for Vref to settle
  delay( 2 );
  // Start conversion
  ADCSRA |= _BV(ADSC);
  // Measuring
  while( bit_is_set( ADCSRA , ADSC ) );

  switchAnalogToDigitalConverterOff();

  // Must read ADCL first
  // It then locks ADCH
  uint8_t low  = ADCL;
  // Unlock both
  uint8_t high = ADCH;

  long result = (high<<8) | low;

  // Calculate Vcc in mV
  // 1125300 = 1.1*1023*1000
  result = 1125300L / result;

  // Return Vcc in mV
  return result;
}

// Set microcontroller to high frequency
void setHighFreq() {
  // Disable interrupts
  cli();
  // Enable prescaler
  CLKPR = (1<<CLKPCE) | (0<<CLKPS3) | (0<<CLKPS2) | (0<<CLKPS1) | (0<<CLKPS0);
  // Divide clock by 1
  CLKPR = (0<<CLKPS3) | (0<<CLKPS2) | (0<<CLKPS1) | (0<<CLKPS0);
  // Enable interrupts
  sei();
}

// Set microcontroller to low frequency
void setLowFreq() {
  // Disable interrupts
  cli();
  // Enable prescaler
  CLKPR = (1<<CLKPCE) | (0<<CLKPS3) | (0<<CLKPS2) | (0<<CLKPS1) | (0<<CLKPS0);
  // Divide clock by 256
  CLKPR = (1<<CLKPS3) | (0<<CLKPS2) | (0<<CLKPS1) | (0<<CLKPS0);
  // Enable interrupts
  sei();
}

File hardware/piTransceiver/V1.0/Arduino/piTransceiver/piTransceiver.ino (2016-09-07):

//
// piTransceiver firmware
//
// @hardware ATtiny85
// @author CYOSP
// @version 1.0.0

// V 1.0.0 2016-05-22
//  Initial release

//
// Includes 
//

// Needed to receive codes over 433 Mhz
#include <RCSwitch.h>
// Serial librarie
#include <AsmTinySerial.h>  

//
// Microcontroller pin mapping
//

// LED pin
#define LED_PIN           PB0
// Pin connected to the 433 Mhz receiver 
#define RECEIVER_433_PIN  PB1
// Pin connected to the serial port of the Raspberry Pi
#define UART_Tx           PB3

// Define serial baud rate for communication with Raspberry Pi
#define UART_BAUDE_RATE   115200

// RCSwitch library
RCSwitch mySwitch = RCSwitch();
// Define a character array able to store code from unsigned long (32 bits) to string
char codeAsString[ 6 ];

//
// Code can be sent several times in order to be sure it will be received
// Here is the necessary to manage it and transmit only once to the Raspberry Pi
//
#define AVOID_REPEAT_CODE_BELOW_MSEC  500
unsigned long previousReceivedTime = 0;
unsigned long previousCode = 0;

void setup()
{
  // Initialize serial communication
  SerialInit( UART_Tx , UART_BAUDE_RATE );

  // Define LED pin state
  pinMode( LED_PIN , OUTPUT );

  // Start first LED flash 
  digitalWrite( LED_PIN , HIGH );
  delay( 1000 );
  digitalWrite( LED_PIN , LOW );

  // Send "Init" string over serial port
  SerialTx( "Init\n" );

  // Wait a moment
  delay( 500 );
  
  // Second LED flash
  digitalWrite( LED_PIN , HIGH );
  delay( 1000 );
  digitalWrite( LED_PIN , LOW );

  // Enable to receive codes
  mySwitch.enableReceive( RECEIVER_433_PIN );
}

void loop()
{
  // A code is available
  if( mySwitch.available() )
  {
    // Get current time
    unsigned long currentTime = millis();
    // Get code received
    unsigned long currentCode = mySwitch.getReceivedValue();

    // Check if it's a new code to manage
    if( currentCode != previousCode && ( (currentTime - previousReceivedTime) > AVOID_REPEAT_CODE_BELOW_MSEC) )
    {
      // Transform code which is a number into a string
      sprintf( codeAsString , "%lu\n", currentCode );

      // Send code over serial port
      SerialTx( codeAsString );

      // Flash LED
      digitalWrite( LED_PIN , HIGH );
      delay( 50 );
      digitalWrite( LED_PIN , LOW );
    }

    // Update backup values
    previousReceivedTime = currentTime;
    previousCode = currentCode;
    
    // It's now possible to receive a new code
    mySwitch.resetAvailable();
  }

}

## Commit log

2016-04-07 Add PCB source code
    [CYTHS.fzz]
2016-04-14 Improve battery life
2016-04-18 Add Arduino microcontroller configuration
2016-04-25 Add PCB image
2016-05-22 Improve sensor id random generation
2016-07-03 Reorganize sensor code
    [CYTHS.fzz]
2016-07-08 Add http://localhost/cyths/sensors
2016-07-08 Manage 'id' parameter for http://localhost/cyths/sensors
2016-07-10 Add a graphic link to each sensor
2016-07-12 Update README thus sensor data format
2016-07-13 Reflect new sensor data format
2016-07-16 Improve Arduino configuration details
2016-07-21 Switch receiver serial port and add log rotation
2016-08-01 Prepare new sensor hardware
    [CYTHS.fzz]
2016-08-28 Add CYTHS 2.0 PCB images
2016-08-29 Add KiCad files for CYTHS 2.0 sensor
    [CYTHS.kicad_pcb, CYTHS.sch]
2016-08-30 Add CYTHS V 2.0 Arduino firmware
2016-09-04 Add piTransceiver hardware
    [piTransceiver.kicad_pcb, piTransceiver.sch]
2016-09-07 Add piTransceiver V 1.0 Arduino firmware
2016-09-09 Add hyperlinks to CYTHS sensor and piTransceiver
2016-09-18 Update README in order to display sensor V 1.0
2016-09-18 Display sensor V 2.0
2016-09-28 Switch can now be disabled
2016-10-01 Add spring antenna
2016-10-02 Fix: call to "switch" URL API
2016-10-05 Add sample of crontab configuration
2016-10-07 Sensor graph takes now all page width
2016-10-22 Update sensors web page
2016-11-02 Add sensors entry in navigation bar
2016-11-12 Add missing 0 for: -.9 <= TEMPERATURE <= .9
2017-01-30 Manage switch with only a sensor attached
2017-03-24 Allow to store sensor data
2017-03-24 Fix: JavaScript error: switchConfigured.sensor is undefined
2017-03-27 Allow to configure sensor info displayed
2017-03-27 Use new API: /API/set/sensor/data/
2017-03-28 Add sample crontab condition
2017-03-30 Switch nodejs binary name from node to nodejs
2017-03-30 Fix: Check sensor existence before to check sensor.id
2017-04-04 Manage empty switch info field
2017-07-13 Remove space in directory names
    [CYTHS.fzz, CYTHS.kicad_pcb, CYTHS.sch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]
2018-09-15 Fix: display switches in loading page instead of the first data refresh
2019-01-19 Log battery percentage value
2019-01-20 Set battery percentage in sensor data
2019-01-20 Battery percentage and indicator can be displayed in sensor info zone
2019-01-21 Fix: Minimum and maximum battery level was inverted
2019-01-22 Store battery percentage inside Round Robin Database
2019-01-23 Add battery percentage to graphics
2019-02-02 Add sensors data to complete demo
    [10.rrd.csv, 20.rrd.csv, 30.rrd.csv]
2021-02-14 Fix: No default switch info label translated when there is no sensor
2021-02-14 Improve switch info default label translation mechanism
2022-08-08 Add dependency libraries installation for sensor V2.0
2022-08-08 Update Arduino configuration + add details on programmer setup and code upload
2022-08-09 Update component links and add power voltage
2022-08-09 Add warning on programmer linked to sensor board
2022-08-10 Sensor id can be chosen using a static variable
2022-08-11 Battery level is updated only each 6 hours instead of each measure
2022-08-12 Add README to sensor
2022-08-13 Improve battery voltage mapping and fact it can only down
2022-08-14 Fix: Code not working for sensor V1.0
    [sensor.ino]
2022-08-17 Display sensors raw data instead of smoothed ones
2022-08-18 Add ATtiny85 pin mapping
2022-10-03 Hide switch with no sensor from sensor view in split mode
2022-10-06 Fix: Switch not displayed on page load
2022-10-11 Update switch info color following outdated sensor data
2022-10-15 Sensor temperature and/or humidity trend can be displayed in info section
2022-12-19 Fix: Incorrect temperature trend with negative values
2023-07-20 Move to container packaging
    [10.rrd.csv, 20.rrd.csv, 30.rrd.csv]
2023-07-22 Fix: Display all sensors graph instead of the asked one
2023-08-01 cyths-update: Avoid Bash error if sensor value received is not registered
2023-10-22 Fix: Temperature matching with value sent
2023-10-23 Add flood sensor capability to V2 sensor
2023-10-24 Add first flood sensor extension description
2023-12-24 Add switch separator and switch with sensor in splited view
    [11.rrd.csv, 21.rrd.csv]
2024-08-09 cyths-update: Move updated date to sensor decoded info in a new log format

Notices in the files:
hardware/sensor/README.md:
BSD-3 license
